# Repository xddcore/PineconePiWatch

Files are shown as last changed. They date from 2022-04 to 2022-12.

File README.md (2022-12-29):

<!--
 * @Author: Chengsen Dong 1034029664@qq.com
 * @Date: 2022-12-29 07:08:10
 * @LastEditors: Chengsen Dong 1034029664@qq.com
 * @LastEditTime: 2022-12-29 07:17:54
 * @FilePath: /undefined/Users/xdd/git_warehouse/PineconePiWatch/README.md
 * @Description: 这是默认设置,请设置`customMade`, 打开koroFileHeader查看配置 进行设置: https://github.com/OBKoro1/koro1FileHeader/wiki/%E9%85%8D%E7%BD%AE
-->
# PineconePi Watch:一个基于ESP32+STC8的物联网手表
## 作者:xddcore(Chengsen Dong)|大二课程系统设计
## Email:1034029664@qq.com
## Github:www.github.com/xddcore
## Version:1.2
## Date:20/04/2021
## 效果视频:https://www.bilibili.com/video/BV1AA411V7fJ?spm_id_from=333.999.0.0
## 中期视频(ppt讲解):https://www.bilibili.com/video/BV1XT4y1P718/?share_source=copy_web&vd_source=e0a08236a93074f4e5ffc9911edd0047

# 项目简介
**PineconePi Watch** ESP32+STC8；6轴陀螺仪+心率+体温；MQTT；双层0603 SMD电路板；两块电路板FPC连接；1.44英寸OLED显示屏；拨动开关；IP5306+500maH可充电锂电池；Type-C可二次开发；

# 项目特性
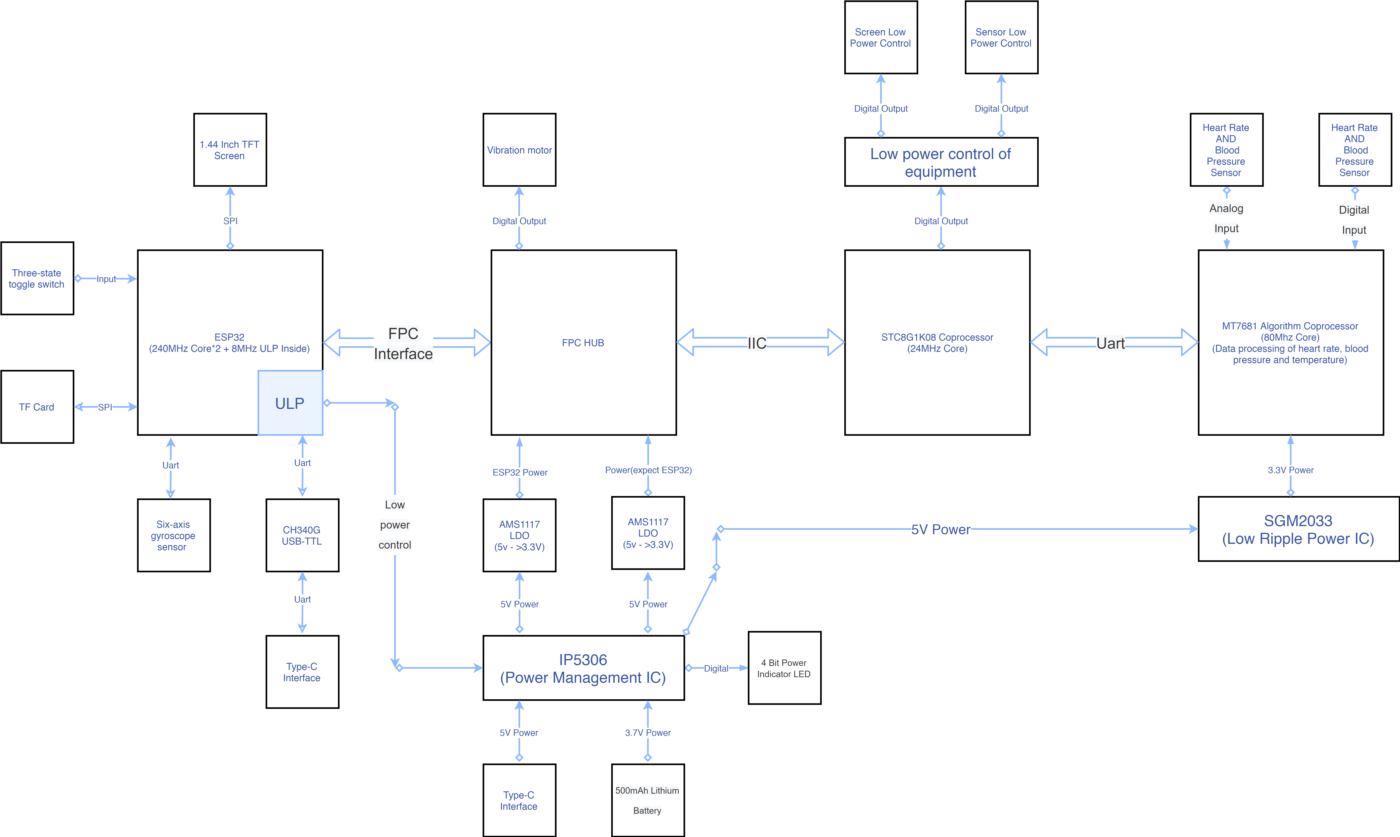
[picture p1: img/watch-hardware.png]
项目硬件框图


为了更加直观的展示项目的硬件结构，将项目硬件框图展示如上。现在将对硬件框图进行详细的介绍：
1.	本设备硬件由3个微控制器，5个核心组成。其中ESP32与STC8协处理器通过FPC排线连接。它们使用IIC通信协议进行通信和数据传输。
2.	设备电源由IP5306电源管理芯片进行管理。IP5306可以根据实际情况自动选择设备电源由TYPE-C接口提供或由内部500mAh锂电池提供。同时，IP5306电源管理芯片还可以为锂电池进行充电，并通过4位LED灯指示设备电量。
3.	程序下载和与计算机的串口通信通过CH340G USB-TTL芯片将USB电平和TTL电平进行转换。
4.	ESP32内部的8MHz ULP处理器主要用于当设备休眠时，控制设备的低功耗功能。
5.	STC8协处理器主要用于处理MT7681算法芯片通过串口传输过来的数据，并将数据通过IIC协议传输至ESP32中。同时STC8协处理器对设备TFT屏幕的电源以及传感器的电源进行控制。
6.	用户通过3状态拨码开关控制设备。
7.	MT7681算法芯片读取心率血压传感器和体温传感器的数据，并通过串口将数据传输给STC8协处理器。

# 软件流程图(充分利用ESP32双核+ULP低功耗小核）

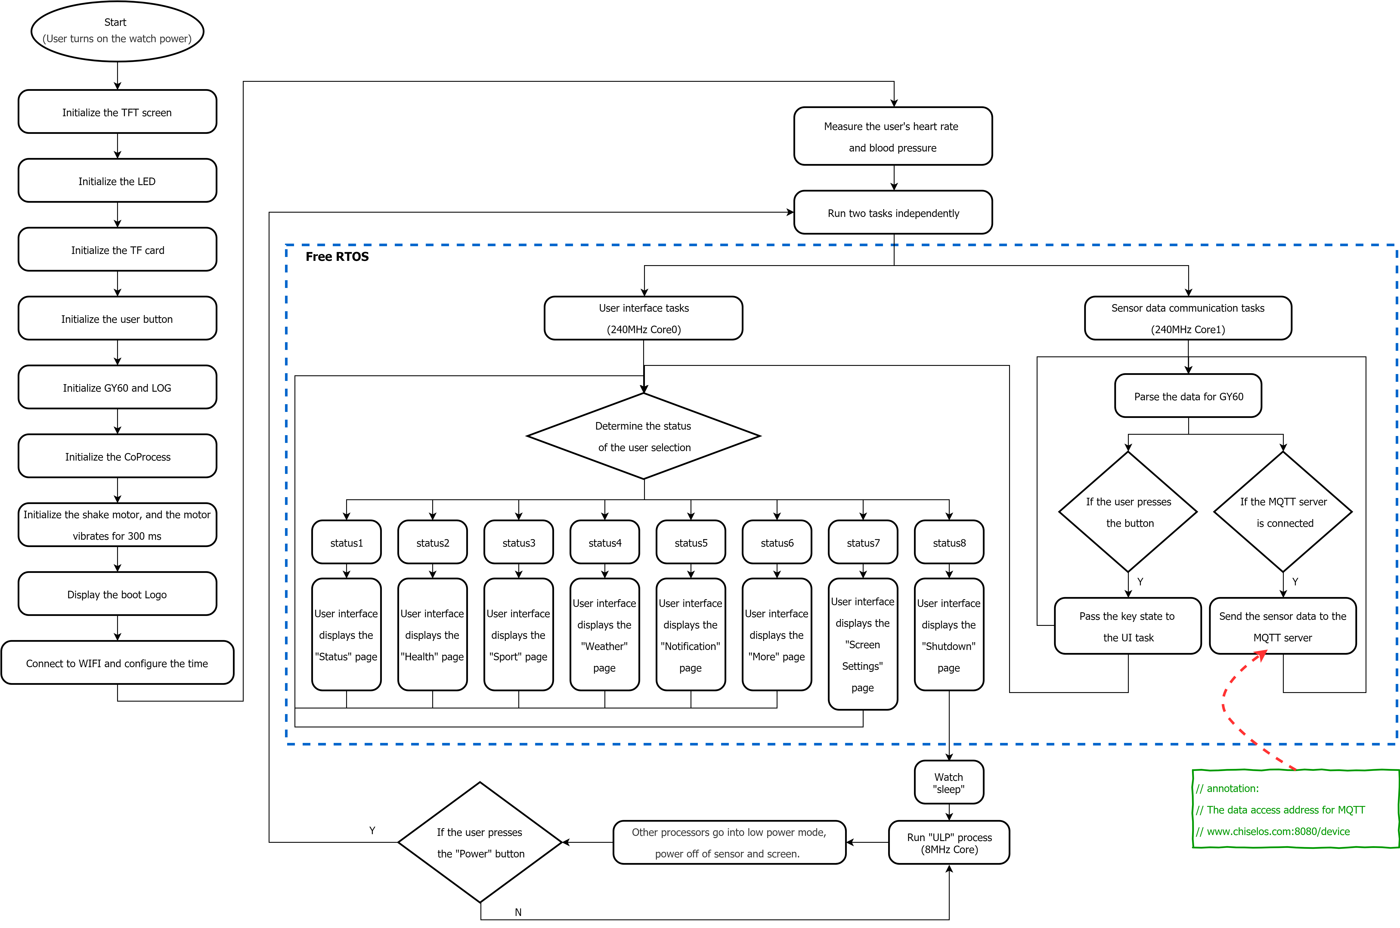
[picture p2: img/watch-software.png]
软件流程图


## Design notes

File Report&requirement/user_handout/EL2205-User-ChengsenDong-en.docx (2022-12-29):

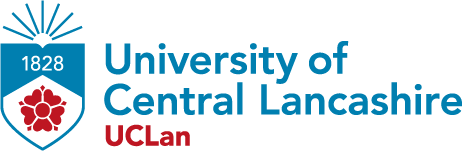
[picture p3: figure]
Where opportunity creates success - University of Central Lancashire

PineconePi Watch

Instruction set & user guide

Chengsen Dong

G20841536

Electronic Systems Applications

EL2205

Zhijie Ding

14/04/2021

I confirm that the present assignment is all my own work and the source of any information and material I have used (including the Internet) has been fully identified and properly acknowledged as required in the School guidelines I have received.

Signed: Chengsen Dong

# 1. How to use PineconePi Watch

## 1.1 Self-test

After PineconePi Watch is turned on, it will start the initialization of each peripheral in turn. At the same time, after completing the initialization of the peripheral, the device will also detect the online status of the peripheral. If the initialization of the peripheral and the online detection of the peripheral are completed, a blue X will be drawn on the corresponding peripheral position on the TFT screen. If there is an error in this process, a blue X will not be drawn on the corresponding peripheral position on the TFT screen. This power-on self-test operation helps users check out the abnormal parts of the device, and facilitates users to troubleshoot problems.

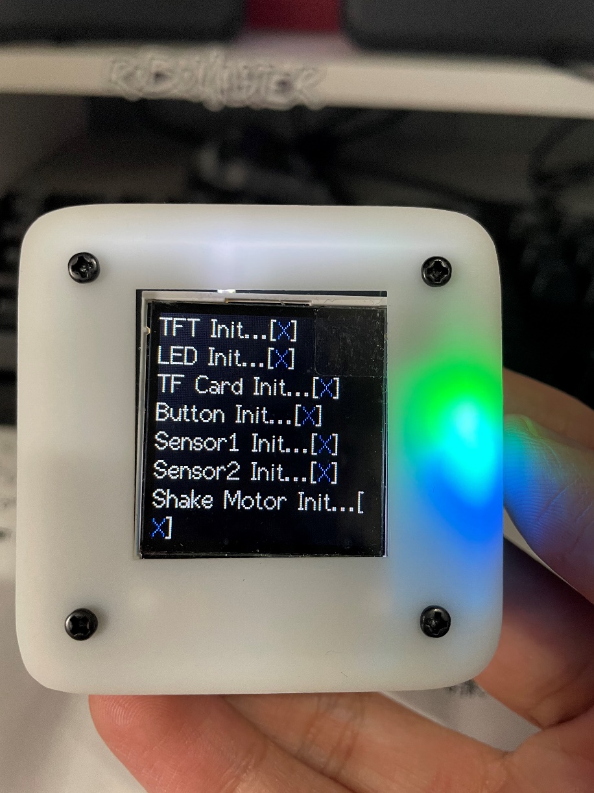
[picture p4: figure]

Figure 1 Power-on self-test

## 1.2 Use the toggle switch to control the device

There is a 3-state toggle switch in the upper left corner of the PineconePi Watch. This toggle switch is used to allow the user to control the device to collect the required sensor data. The control logic of the toggle switch is as follows: when the toggle switch is moved down, the device jumps to the next interface; when the toggle switch is moved up, the device jumps to the previous interface; when the toggle switch is pressed, The device enters the secondary menu interface of the current interface.

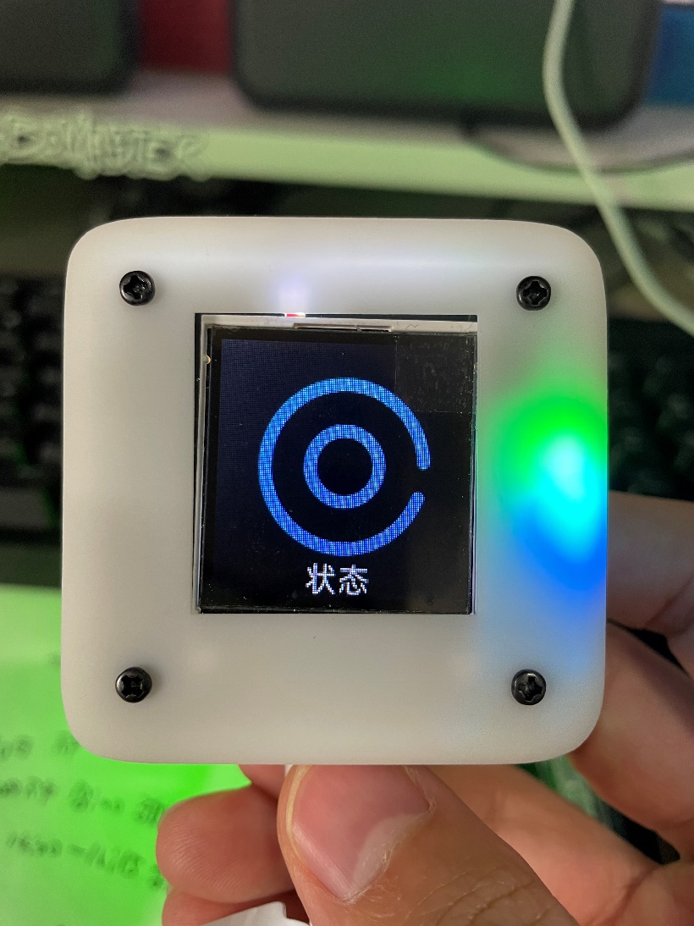
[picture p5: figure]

Figure 2 Toggle switch control equipment

## 1.3 Viewing sensor data

To facilitate the reading of sensor values, I put all sensor data on the 8th interface for display. At the same time, in order to enable the sensor data to be transmitted to the MQTT server through the WIFI hotspot connected when the machine is turned on, and to display the sensor data on the Web page. I added NTP time service to the 8th interface to synchronously detect the WIFI connection. If the Dongba District (Beijing) time can be displayed normally on the 8th interface, it proves that the device has been connected to the Internet at this time.

In the 8th interface, the highest blood pressure, lowest blood pressure, heart rate, body temperature will be displayed; X-axis angle and acceleration; Y-axis angle and acceleration; Z-axis angle and acceleration.

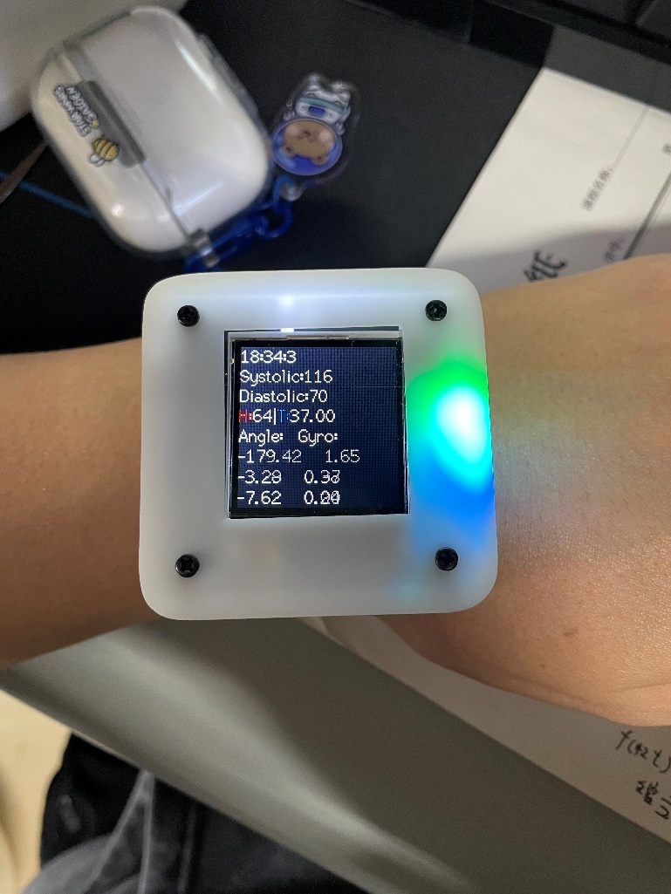
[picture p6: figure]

Figure 3 View of sensor data

## 1.4 View device data on the web page

When the device is on the 8th interface, the device will send the collected sensor data to the MQTT server. At the same time, the web server Django script that has been running will display the data monitored from MQTT to the web page (web page address: www.chiselos.com:8080/device/). Every time the web page is refreshed, the device will report the latest sensor data to the MQTT server, and this latest data will be used to update the data displayed on the web page.

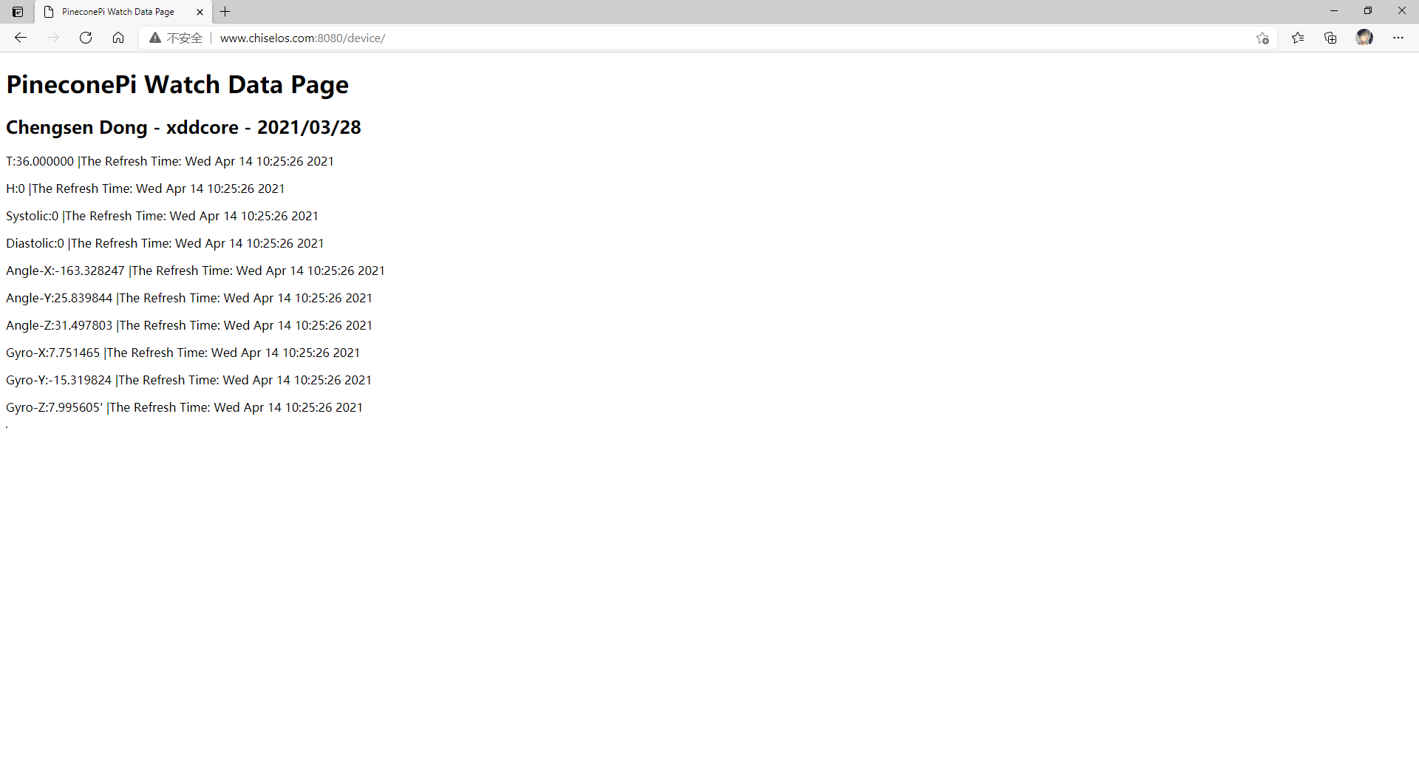
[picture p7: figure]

Figure 4 Web page data view

## 1.5 Update device firmware

PineconePi Watch comes with an automatic firmware download circuit inside. When updating the firmware, you only need to connect the device and the computer through a TYPE-C cable. Then you can download the compiled .bin program file to the device. At the same time, the device also supports an over-the-air upgrade (OTA) function. As long as the device is connected to the Internet, it can compare its firmware version number with the firmware version number on the server. If the device version number is lower than the server version number. The device will automatically download the latest firmware from the server to the device TF card, and then the device will burn the firmware in the TF card into the ESP32 on-chip FLASH.

## 1.6 Battery indicator and charging

There are 4 power indicator lights on the PCB at the bottom of the PineconePi Watch, and each LED light represents 25% of the power. For example, when the power is 50%-75%, 2 LEDs will light up; when the power is 75%-100%, 3 LEDs will light up; when the power reaches 100%, there will be 4 LEDs Glow.

PineconePi Watch has a powerful IP5306 power management chip inside. Just connect the TYPE-C cable to the 5V DC power supply and you can start charging the device. When the device is charging, the corresponding power LED light will flash to indicate. When it is full, the LED light will no longer flash.

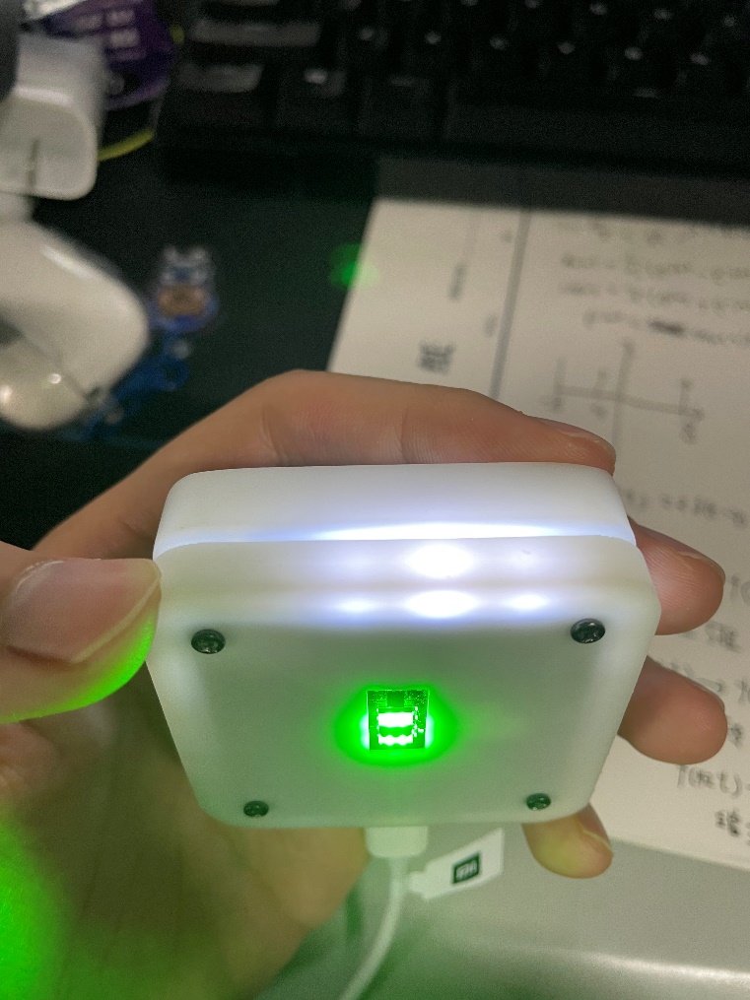
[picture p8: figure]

Figure 5 Power and charging indication

# 2. Troubleshooting Guide

Due to the complexity of this equipment, the following failures occur when in use, please return it to me for repair. The following failure guide only helps users to know the cause of the failure:

## 2.1 Self-test failed

When an error occurs in the device's self-test, please troubleshoot the fault in the following ways:

1. Sensor1 self-detection error. Possible reasons for this error:

1. ICM 6-axis gyroscope sensor is not connected

2. Sensor2 self-test error. Possible reasons for this error:

1. STC8 coprocessor is not working

2. STC8 coprocessor

## 2.2 Graphical interface cannot be displayed

When the graphical interface of the device cannot be displayed, the possible reasons for this error:

1. The TF card with system file resources is not inserted

2. TF insertion appears loose

3. The TF card does not contain system file resources

## 2.3 Unable to get sensor value

When the device cannot display sensor data on the 8th interface, the possible reasons for this error are:

1. The device is not connected to WIFI

2. WIFI cannot connect to the Internet

3. NTP time service failed

4. Sensor failure

## 2.4 Web page access failed

When the web page cannot be accessed, the possible reasons for this error:

1. The access URL is incorrectly entered

2. The web server is not working

3. Web server failure

## 2.5 Unable to start device

When the device fails to start, the possible reasons for this error:

1. The internal lithium battery power of the device is exhausted

2. Equipment failure

3. The equipment power management circuit works abnormally

Running head 2

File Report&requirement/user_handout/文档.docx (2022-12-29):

在PineconePi Watch开机后，便会依次开始对每一个外设的初始化。同时，在完成对外设的初始化后，设备还会对外设的在线情况进行检测。如果外设初始化和外设在线检测完成，便会在TFT屏幕上的相应外设位置绘制蓝色X。如果这一个过程出现错误，便不会在TFT屏幕上的相应外设位置绘制蓝色X。这个上电自检测操作有助于帮助用户检查出设备中运行不正常的部分，方便用户排除问题。

PineconePi Watch左上角带有一颗3状态拨动开关。这颗拨动开关用于让用户控制设备采集需要的传感器数据。拨动开关的控制逻辑如下：当波动开关向下拨动时，设备跳转到下一个界面；当拨动开关向上拨动时，设备跳转到上一个界面；当拨动开关按下时，设备进入当前界面的二级菜单界面。

为了方便读取传感器数值，我将所有传感器数据放在8号界面中显示。同时，为了使传感器数据能够通过开机时连接的WIFI热点传输至MQTT服务器中，并把传感器数据显示在Web网页上面。我在8号界面中加入了NTP授时来同步检测WIFI联通情况。如果在8号界面中能够正常显示东八区(北京)时间，则证明此时设备已经连接上互联网。

在8号界面中，将会显示最高血压，最低血压，心率，体温；X轴角度和加速度；Y轴角度和加速度；Z轴角度和加速度。

当设备处于8号界面时，设备会将采集到的传感器数据发送至MQTT服务器中。同时，一直处于运行状态中的Web服务器Django脚本将会把从MQTT中监听到的数据显示到Web网页中（网页地址：www.chiselos.com:8080/device/）。每刷新一次网页，设备将会把最新的传感器数据上报到MQTT服务器中，这个最新的数据将用于更新Web网页上显示的数据。

PineconePi Watch内部自带固件自动下载电路。更新固件时，只需要将设备与计算机通过TYPE-C线缆进行连接。之后便可以将编译过后的.bin程序文件下载到设备中。同时，设备还支持空中升级(OTA)功能，设备只要连接上互联网，便可以将自己的固件版本号与服务器上的固件版本号进行对比。如果设备版本号低于服务器版本号。设备将会自动将最新的固件从服务器中下载到设备TF卡中，设备再将TF卡中的固件烧入ESP32片内FLASH中。

PineconePi Watch底部PCB上带有4颗电量指示灯，每颗LED灯代表25%的电量。例如当电量为50%-75%时，将会有2颗LED发光；当电量为75%-100%时，将会有3颗LED发光；当电量达到100%时，将会有4颗LED发光。

PineconePi Watch内部带有强大的IP5306电源管理芯片。只需将TYPE-C线缆与5V DC电源连接，便可以开始为设备充电。设备充电时，对应的电量LED灯将会闪烁提示。充满时，LED灯将不会再闪烁。

——

当设备在自检测中出现错误时，请以以下方式排除故障：

1. Sensor1自检测错误。可能导致这个错误的原因：
1. ICM 6轴陀螺仪传感器未连接

2．Sensor2自检测错误。可能导致这个错误的原因：

1. STC8 协处理器未工作

2.STC8协处理器

当设备图形化界面无法显示时，可能导致这个错误的原因：

1. 装有系统文件资源的TF卡未插入
2. TF插入出现松动
3. TF卡中未含有系统文件资源

当设备无法在8号界面上显示传感器数据时，可能导致这个错误的原因：

1. 设备未连接WIFI
2. WIFI无法连接互联网
3. NTP授时失败
4. 传感器故障

当Web网页无法访问时，可能导致这个错误的原因：

1. 未正确输入访问网址
2. Web服务器未工作
3. Web服务器故障

当设备无法启动时，可能导致这个错误的原因：

1． 设备内部锂电池电源耗尽
2． 设备故障
3． 设备电源管理电路工作异常

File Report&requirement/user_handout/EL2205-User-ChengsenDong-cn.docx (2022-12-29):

Where opportunity creates success - University of Central Lancashire

PineconePi Watch

Instruction set & user guide

Chengsen Dong

G20841536

Electronic Systems Applications

EL2205

Zhijie Ding

14/04/2021

I confirm that the present assignment is all my own work and the source of any information and material I have used (including the Internet) has been fully identified and properly acknowledged as required in the School guidelines I have received.

Signed: Chengsen Dong

# 1. PineconePi Watch使用指南

## 1.1 开机自检测

在PineconePi Watch开机后，便会依次开始对每一个外设的初始化。同时，在完成对外设的初始化后，设备还会对外设的在线情况进行检测。如果外设初始化和外设在线检测完成，便会在TFT屏幕上的相应外设位置绘制蓝色X。如果这一个过程出现错误，便不会在TFT屏幕上的相应外设位置绘制蓝色X。这个上电自检测操作有助于帮助用户检查出设备中运行不正常的部分，方便用户排除问题。


图1 开机自检测

## 1.2 使用拨动开关控制设备

PineconePi Watch左上角带有一颗3状态拨动开关。这颗拨动开关用于让用户控制设备采集需要的传感器数据。拨动开关的控制逻辑如下：当波动开关向下拨动时，设备跳转到下一个界面；当拨动开关向上拨动时，设备跳转到上一个界面；当拨动开关按下时，设备进入当前界面的二级菜单界面。


图2 拨动开关控制设备

## 1.3 传感器数据查看

为了方便读取传感器数值，我将所有传感器数据放在8号界面中显示。同时，为了使传感器数据能够通过开机时连接的WIFI热点传输至MQTT服务器中，并把传感器数据显示在Web网页上面。我在8号界面中加入了NTP授时来同步检测WIFI联通情况。如果在8号界面中能够正常显示东八区(北京)时间，则证明此时设备已经连接上互联网。

在8号界面中，将会显示最高血压，最低血压，心率，体温；X轴角度和加速度；Y轴角度和加速度；Z轴角度和加速度。


图3 传感器数据查看

## 1.4 Web网页查看设备数据

当设备处于8号界面时，设备会将采集到的传感器数据发送至MQTT服务器中。同时，一直处于运行状态中的Web服务器Django脚本将会把从MQTT中监听到的数据显示到Web网页中（网页地址：www.chiselos.com:8080/device/）。每刷新一次网页，设备将会把最新的传感器数据上报到MQTT服务器中，这个最新的数据将用于更新Web网页上显示的数据。


图4 Web 网页数据查看

## 1.5 更新设备固件

PineconePi Watch内部自带固件自动下载电路。更新固件时，只需要将设备与计算机通过TYPE-C线缆进行连接。之后便可以将编译过后的.bin程序文件下载到设备中。同时，设备还支持空中升级(OTA)功能，设备只要连接上互联网，便可以将自己的固件版本号与服务器上的固件版本号进行对比。如果设备版本号低于服务器版本号。设备将会自动将最新的固件从服务器中下载到设备TF卡中，设备再将TF卡中的固件烧入ESP32片内FLASH中。

## 1.6 电量指示与充电

PineconePi Watch底部PCB上带有4颗电量指示灯，每颗LED灯代表25%的电量。例如当电量为50%-75%时，将会有2颗LED发光；当电量为75%-100%时，将会有3颗LED发光；当电量达到100%时，将会有4颗LED发光。

PineconePi Watch内部带有强大的IP5306电源管理芯片。只需将TYPE-C线缆与5V DC电源连接，便可以开始为设备充电。设备充电时，对应的电量LED灯将会闪烁提示。充满时，LED灯将不会再闪烁。


图5 电量与充电指示

# 2. 故障排除指南

## 2.1自检测失败

当设备在自检测中出现错误时，请以以下方式排除故障：

1.Sensor1自检测错误。可能导致这个错误的原因：

1.ICM 6轴陀螺仪传感器未连接

2．Sensor2自检测错误。可能导致这个错误的原因：

1. STC8 协处理器未工作

2.STC8协处理器

## 2.2 图形界面无法显示

当设备图形化界面无法显示时，可能导致这个错误的原因：

1.装有系统文件资源的TF卡未插入

2.TF插入出现松动

3.TF卡中未含有系统文件资源

## 2.3 无法获取传感器数值

当设备无法在8号界面上显示传感器数据时，可能导致这个错误的原因：

1.设备未连接WIFI

2.WIFI无法连接互联网

3.NTP授时失败

4.传感器故障

## 2.4 Web网页访问失败

当Web网页无法访问时，可能导致这个错误的原因：

1.未正确输入访问网址

2.Web服务器未工作

3.Web服务器故障

## 2.5 无法启动设备

当设备无法启动时，可能导致这个错误的原因：

1．设备内部锂电池电源耗尽

2．设备故障

3．设备电源管理电路工作异常

Running head 2

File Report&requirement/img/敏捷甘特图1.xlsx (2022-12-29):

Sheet: 甘特
在此工作表中创建甘特图。 在单元格 B1 中输入此项目的标题。 图例标题位于单元格 I1 中。 有关如何使用此工作表（包括屏幕阅读器的说明）以及此工作簿作者的信息包含在“关于”工作表中。 继续向下浏览 A 列，获取进一步指示。 | PineconePi Watch |  |  |  |  |  | Legend:
在单元格 B2 中输入公司名称。 图例位于单元格 I2 到 AC2 中。 | Chengsen Dong |  |  |  |  |  | Low priority |  |  |  |  | Medium priority |  |  |  |  | High priority |  |  |  |  | 高风险 |  |  |  |  | 未分配
在单元格 B3 中输入项目负责人的姓名。在单元格 F3 中输入项目开始日期，或允许示例公式从“甘特数据”表中查找最小日期值。 项目开始日期：标签位于单元格 D3 中。 | EL2205 |  | Project start date: |  | 2020-11-04
滚动增量位于单元格 F4 中。 从单元格 I4 开始到单元格 BL4，显示第 5 行中日期的月份。 请勿修改这些单元格。它们根据单元格 F3 中的项目开始日期自动更新。 |  |  | Scroll delta: |  | 0 |  | 11月 |  |  |  |  |  |  |  |  |  |  |  |  |  |  |  |  |  |  |  |  |  |  |  |  |  |  |  | 12月
单元格 I5 到 BL5 包含每个日期单元格上方单元格块中表示的“月”的当月日期数字，这些数字是自动计算得出的。 请勿修改这些单元格。 今天的日期带有红色（十六进制 #AD3815）轮廓（从第 5 行中显示今天日期的列及至项目安排结尾的该列）。 |  |  |  |  |  |  | 2020-11-04 | 2020-11-05 | 2020-11-06 | 2020-11-07 | 2020-11-08 | 2020-11-09 | 2020-11-10 | 2020-11-11 | 2020-11-12 | 2020-11-13 | 2020-11-14 | 2020-11-15 | 2020-11-16 | 2020-11-17 | 2020-11-18 | 2020-11-19 | 2020-11-20 | 2020-11-21 | 2020-11-22 | 2020-11-23 | 2020-11-24 | 2020-11-25 | 2020-11-26 | 2020-11-27 | 2020-11-28 | 2020-11-29 | 2020-11-30 | 2020-12-01 | 2020-12-02 | 2020-12-03 | 2020-12-04 | 2020-12-05 | 2020-12-06 | 2020-12-07 | 2020-12-08 | 2020-12-09 | 2020-12-10 | 2020-12-11 | 2020-12-12 | 2020-12-13 | 2020-12-14 | 2020-12-15 | 2020-12-16 | 2020-12-17 | 2020-12-18 | 2020-12-19 | 2020-12-20 | 2020-12-21 | 2020-12-22 | 2020-12-23 | 2020-12-24 | 2020-12-25
滚动条位于单元格 I6 到 BL6 中。数据分页增量定义为一次 2 页，可以在控制栏的设置中配置该增量。 若要在时间线中向前或向后跳转，请在单元格 F4 中输入 0 或更大的值。 值为 0 会转到图表的开头。
此行包含其后面的项目安排的标题。 从 B7 导航到 BL7 以听取内容。该标题上方日期一周中每一天的首字母，从单元格 I7 开始，直到单元格 BL7。 所有项目时间线制图都是根据“里程碑”表中输入的类别、开始日期和天数自动生成的。 | Mission statement | category | personnel | progress | Start date | Number of days | 三 | 四 | 五 | 六 | 日 | 一 | 二 | 三 | 四 | 五 | 六 | 日 | 一 | 二 | 三 | 四 | 五 | 六 | 日 | 一 | 二 | 三 | 四 | 五 | 六 | 日 | 一 | 二 | 三 | 四 | 五 | 六 | 日 | 一 | 二 | 三 | 四 | 五 | 六 | 日 | 一 | 二 | 三 | 四 | 五 | 六 | 日 | 一 | 二 | 三 | 四 | 五
请勿删除此行。隐藏了此行，以保留用于突出显示项目安排中当天的公式。
在单元格 B9 到 G9 中输入项目信息。 示例数据位于单元格 B9 到 G33 中。 输入“里程碑说明”，从下拉列表中选择一个类别，为某人分配责任人，输入进度、开始日期和任务的天数以开始制图。 下一条指示位于单元格 A34 中。 | Hardware development
 | 元件选型 | 中等风险 | ChengsenDong | 100% | 2020-11-04 | 6
 | 原理图绘制 | 中等风险 | ChengsenDong | 100% | 2020-11-10 | 4
 | PCB绘制 | 中等风险 | ChengsenDong | 100% | 2020-11-14 | 6
 | PCB焊接 | 中等风险 | ChengsenDong | 100% | 2020-11-20 | 2
 | 外壳设计 | 中等风险 | ChengsenDong | 100% | 2020-11-22 | 2
 | 整体组装 | 中等风险 | ChengsenDong | 100% | 2020-11-24 | 1
 | Software development
 | ESP32软件编写 | 低风险 | ChengsenDong | 100% | 2020-11-25 | 5
 | STC协处理器软件编写 | 低风险 | ChengsenDong | 100% | 2020-11-30 | 3
 | Web服务器代码编写 | 低风险 | ChengsenDong | 100% | 2020-12-03 | 3
 | 整体软件编写 | 低风险 | ChengsenDong | 100% | 2020-12-06 | 2
 | Test
 | 硬件测试 | 步入正轨 | ChengsenDong | 100% | 2020-12-08 | 4
 | Web服务器测试 | 步入正轨 | ChengsenDong | 100% | 2020-12-12 | 2
 | 整体测试 | 步入正轨 | ChengsenDong | 100% | 2020-12-14 | 3
 | Report writing
 | Development Report Preparation | 高风险 | ChengsenDong | 100% | 2020-12-17 | 5
 | User manual preparation | 高风险 | ChengsenDong | 100% | 2020-12-22 | 3
这是一个空行

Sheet: 关于
关于此模板
此模板提供了一种创建甘特图的简单方法，可帮助直观呈现和跟踪项目。只需输入任务说明，选择一种类别（“目标”、“里程碑”、“步入正轨”、“低风险”、“中等风险”、“高风险”），然后输入任务完成百分比进度、开始日期和完成任务的天数。甘特图填充完毕，并经过颜色编码，可帮助区分各种类别。通过滚动条可滚动时间线。通过插入新行插入新任务。
屏幕阅读器指南
此工作簿中有 2 个工作表。 甘特图 关于 每个工作表的指示文本位于每个工作表中自单元格 A1 开始的 A 列中。这些指示都使用隐藏文本编写。每个步骤均提供相应指示，引导阅读者查看行中的相应信息。除非另有明确指示，否则会在单元格 A2、A3 等后续单元格中持续指示相应步骤。例如，指示文本可能显示为“转到单元格 A6”以执行下一步操作。 将不会打印此隐藏文本。 若要从工作表删除这些指示，只需删除 A 列即可。
这是此工作表中的最后一条指示。
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

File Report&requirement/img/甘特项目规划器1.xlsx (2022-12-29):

Project Schedule
在右侧选择要突出显示的周期。描述图表的图例如下所示。 |  |  |  |  | 周期突出显示： | 1 |  |  | 计划工期 |  |  |  |  |  | 实际开始时间 |  |  |  |  | 完成百分比 |  |  |  |  | 实际（超出计划） |  |  |  |  |  |  |  | 完成（超出计划）百分比
活动 | 计划开始时间 | 计划工期 | 实际开始时间 | 实际工期 | 完成百分比 | 周期
 |  |  |  |  |  | 1 | 2 | 3 | 4 | 5 | 6 | 7 | 8 | 9 | 10 | 11 | 12 | 13 | 14 | 15 | 16 | 17 | 18 | 19 | 20 | 21 | 22 | 23 | 24 | 25 | 26 | 27 | 28 | 29 | 30 | 31 | 32 | 33 | 34 | 35 | 36 | 37 | 38 | 39 | 40 | 41 | 42 | 43 | 44 | 45 | 46 | 47 | 48 | 49 | 50 | 51 | 52 | 53
活动 01 | 1 | 5 | 1 | 4 | 25%
活动 02 | 1 | 6 | 1 | 6 | 100%
活动 03 | 2 | 4 | 2 | 5 | 35%
活动 04 | 4 | 8 | 4 | 6 | 10%
活动 05 | 4 | 2 | 4 | 8 | 85%
活动 06 | 4 | 3 | 4 | 6 | 85%
活动 07 | 5 | 4 | 5 | 3 | 50%
活动 08 | 5 | 2 | 5 | 5 | 60%
活动 09 | 5 | 2 | 5 | 6 | 75%
活动 10 | 6 | 5 | 6 | 7 | 100%
活动 11 | 6 | 1 | 5 | 8 | 60%
活动 12 | 9 | 3 | 9 | 3 | 0%
活动 13 | 9 | 6 | 9 | 7 | 50%
活动 14 | 9 | 3 | 9 | 1 | 0%
活动 15 | 9 | 4 | 8 | 5 | 1%
活动 16 | 10 | 5 | 10 | 3 | 80%
活动 17 | 11 | 2 | 11 | 5 | 0%
活动 18 | 12 | 6 | 12 | 7 | 0%
活动 19 | 12 | 1 | 12 | 5 | 0%
活动 20 | 14 | 5 | 14 | 6 | 0%
活动 21 | 14 | 8 | 14 | 2 | 44%
活动 22 | 14 | 7 | 14 | 3 | 0%
活动 23 | 15 | 4 | 15 | 8 | 12%
活动 24 | 15 | 5 | 15 | 3 | 5%
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

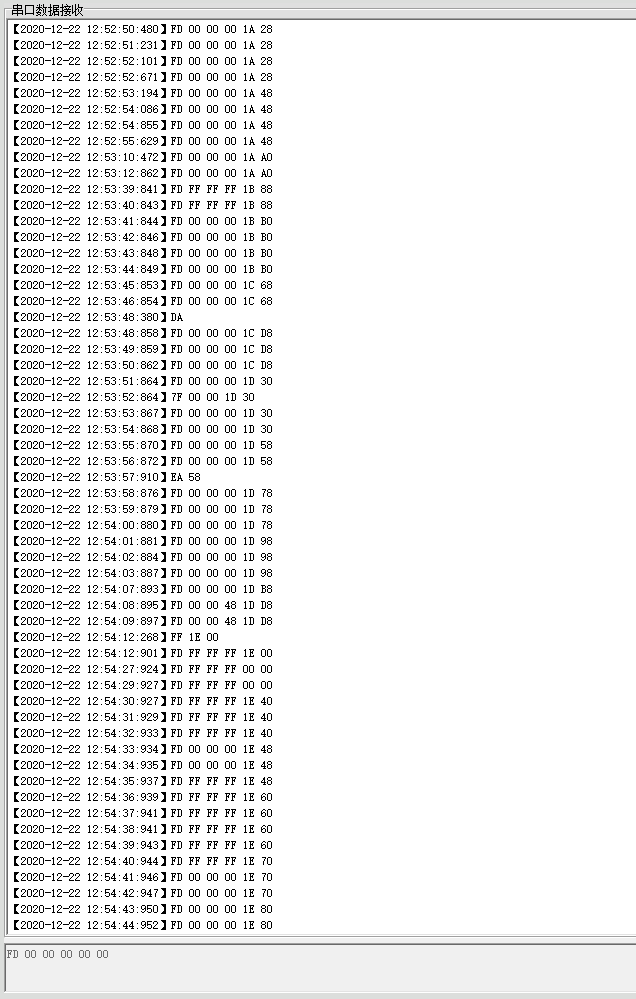
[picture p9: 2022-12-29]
Report&requirement/img/心率回传.png

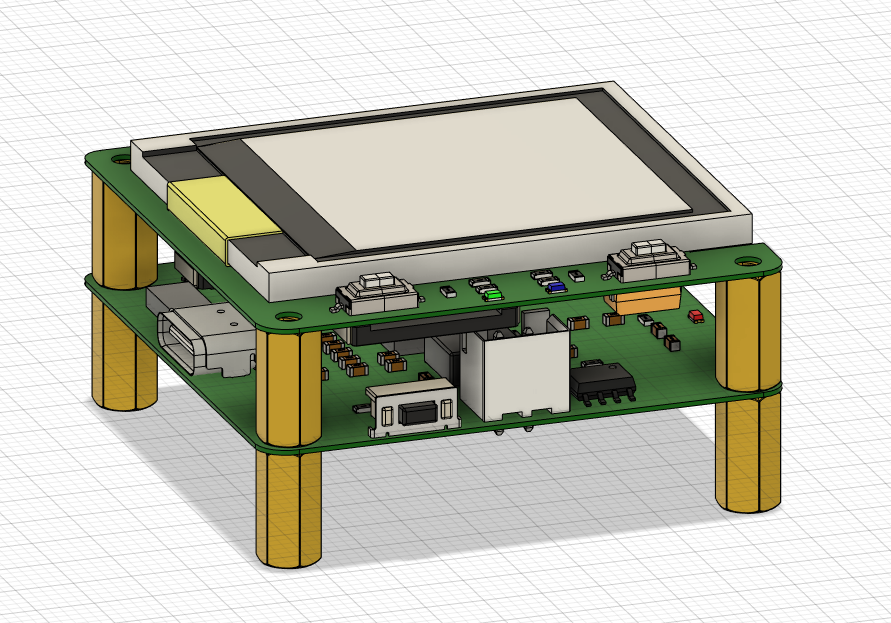
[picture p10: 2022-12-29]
Report&requirement/img/PCB3d仿真图2.png

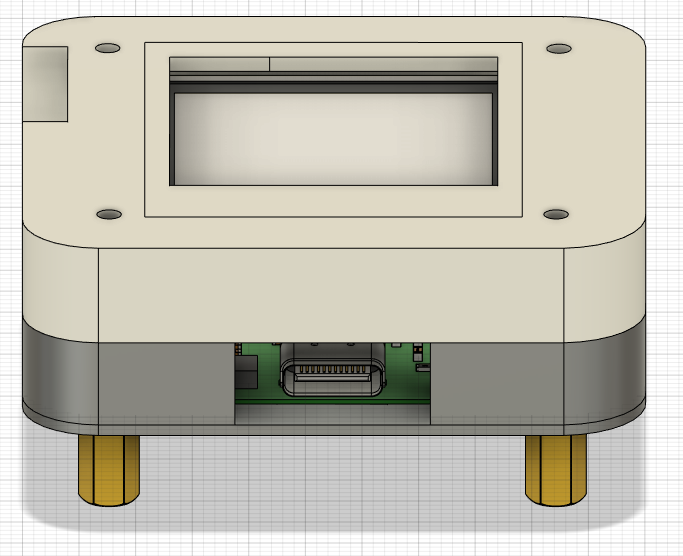
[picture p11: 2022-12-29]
Report&requirement/img/带外壳3d仿真图.png

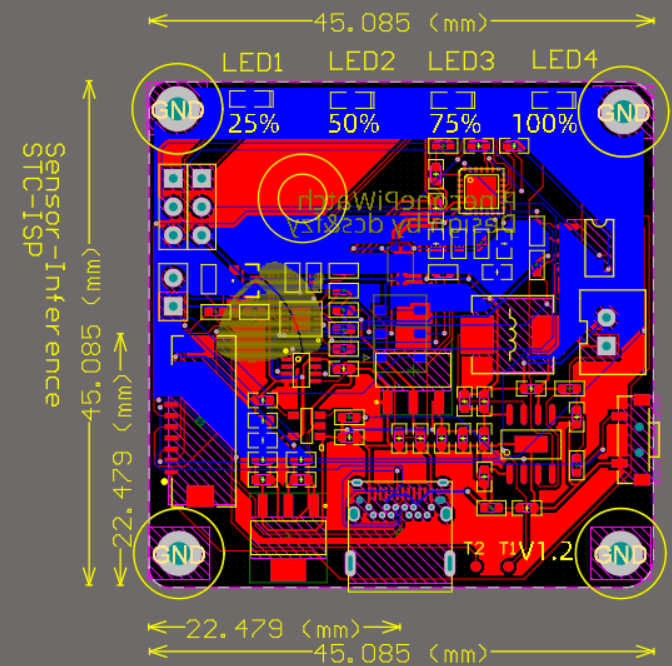
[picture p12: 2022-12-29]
Report&requirement/img/BOTTOM-PCB.png

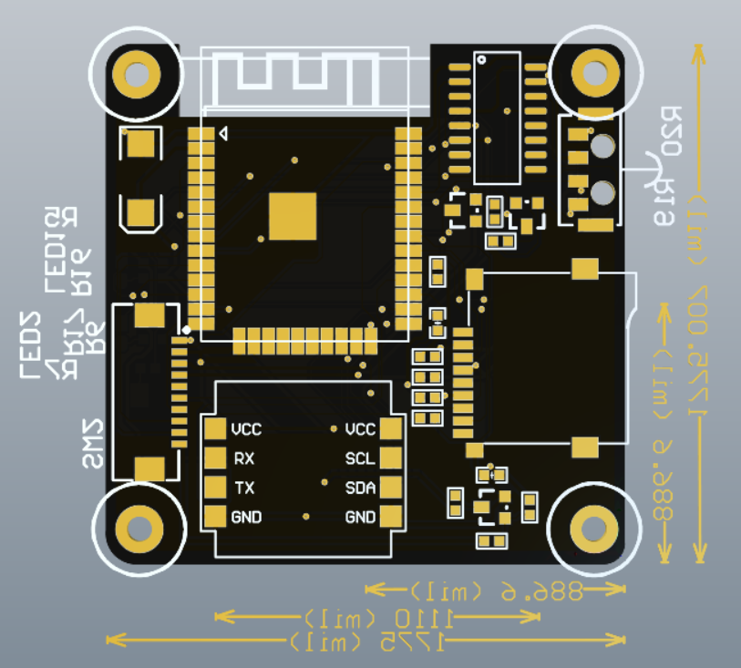
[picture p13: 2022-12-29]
Report&requirement/img/TOP-PCB-2.png

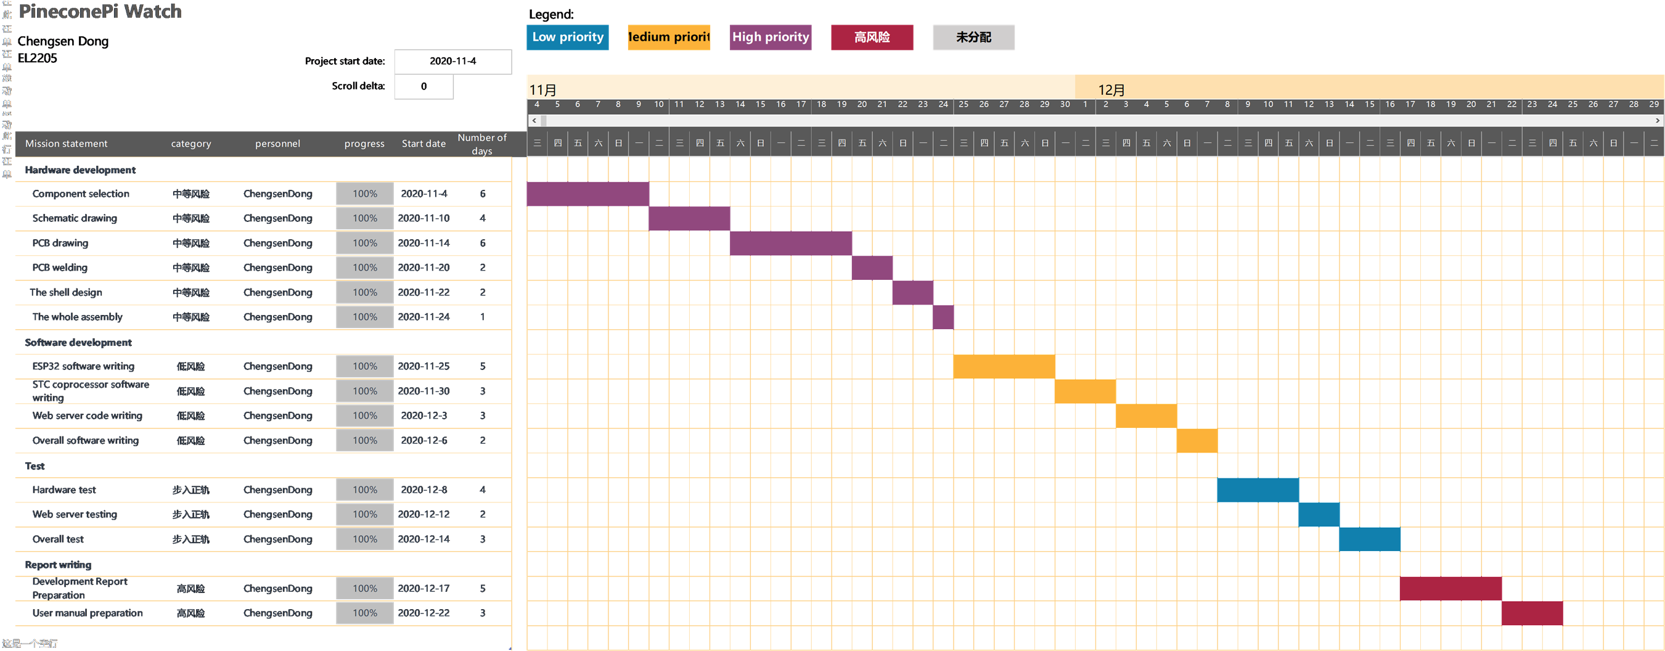
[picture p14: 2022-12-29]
Report&requirement/img/甘特图.png

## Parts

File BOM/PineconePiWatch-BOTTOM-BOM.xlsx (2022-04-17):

Comment | Description | Designator | Footprint | LibRef | Quantity
电池接口 | Header, 2-Pin, Right Angle | BT1 | XH2.54-LI-2P | Header 2H | 1
10uF | Capacitor | C1, C2, C6, C7, C8, C10, C16, C22, C24 | C 0603_L | Cap | 9
22uF | Capacitor | C3, C4, C5 | C 0603_L | Cap | 3
0.1uF | Capacitor | C9, C11, C23, C25 | C 0603_L | Cap | 4
100nF | Capacitor | C12, C13, C14, C15, C17, C21 | C 0603_L | Cap, Cap_1 | 6
220nF | Capacitor | C18 | C 0603_L | Cap_1 | 1
2.2uF | Capacitor | C19 | C 0603_L | Cap_1 | 1
2.2nF | Capacitor | C20 | C 0603_L | Cap_1 | 1
HDR-1X10 | 10P接插件 | FPC1 | FPC1.0-2H-WS-10P | Header 10 | 1
1uH | Inductor | L1 | L-SMD-0630 | Inductor | 1
25% | Typical INFRARED GaAs LED | LED1 | LED 0603R | LED0 | 1
50% | Typical INFRARED GaAs LED | LED2 | LED 0603R | LED0 | 1
75% | Typical INFRARED GaAs LED | LED3 | LED 0603R | LED0 | 1
100% | Typical INFRARED GaAs LED | LED4 | LED 0603R | LED0 | 1
SS8050 | 高频放大-NPN型 | Q1 | SOT-23 | 8050-SMD | 1
2R | Resistor | R1, R2 | R 0603_L | Res2 | 2
10K | Resistor, 贴片电阻 | R3, R5, R9, R22 | R 0603_L | Res2, R | 4
1K | 贴片电阻 | R4 | R 0603_L | R | 1
10 | 贴片电阻 | R6 | R 0603_L | R | 1
4.7K | 贴片电阻 | R7, R8 | R 0603_L | R | 2
100R | Resistor | R10, R11 | C 0603_L | Res2 | 2
0 | Resistor | R12 | R 0603-HP_L | Res2 | 1
120K | Resistor | R13 | R 0603_L | Res2 | 1
22K | Resistor | R14 | R 0603_L | Res2 | 1
3.3K | Resistor | R15 | R 0603_L | Res2 | 1
7.5M | Resistor | R16 | R 0603_L | Res2 | 1
6.2M | Resistor | R17 | R 0603_L | Res2 | 1
4.7M | Resistor | R18 | R 0603_L | Res2 | 1
3.3M | Resistor | R19 | R 0603_L | Res2 | 1
160R | Resistor | R20, R21 | R 0603_L | Res2 | 2
HDR-1X3 | 3P接插件 | Sensor-Inference, STC-ISP | HDR2.54-LI-3P | Header 3 | 2
3x6x5 | 3x6轻触开关 | SW1 | TSW 3*6*4.3-S-W | TSW 3x6 | 1
Test_Point |  | T1, T2 | TP_1_0MM | TP | 2
IP5306 |  | U1 | IP5306 | IP5306 | 1
AMS1117-3V3 | 三端稳压芯片 | U2, U10 | SOT223_L | AMS1117 | 2
STC8G1K08-SOP8 |  | U3 | SOP8 | STC8G1K08-SOP8 | 1
SFB9712-QFN28 |  | U4 | SFB9712 | SFB9712-QFN28 | 1
BL919833BA |  | U5 | BL9198 | BL919833BA | 1
hr6816 |  | U6 | HR6816 | hr6816 | 1
YK1801 |  | U7 | YK1801 | YK1801 | 1
HR6707 |  | U8 | HR6707 | HR6707 | 1
wd3703 |  | U9 | WD3703 | wd3703 | 1
USB-C | USB-C型母接口 | USB-C | type-c 24p 前插后贴 | USB-C/S | 1
HDR-1X2 | 2P接插件 | Vibration motor | HDR2.54-LI-2P | Header 2 | 1

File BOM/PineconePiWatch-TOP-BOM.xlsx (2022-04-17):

Comment | Description | Designator | Footprint | LibRef | Quantity
TXD144CF | 1.44寸TFT | 1.4TFT_128_128 | TXD144CF | TXD144CF | 1
1uF | 贴片电容 | C1 | C 0603_L | C | 1
100uF/10V | 贴片电解电容 | C2 | CM C(5*5.4) | CE_SMD | 1
104 | 贴片电容 | C3 | C 0603_L | C | 1
HDR-1X10 | 10P接插件 | FPC1 | FPC1.0-2H-WS-10P | Header 10 | 1
HDR-1X8 | 8P接插件 | GY-62 | 维特智能GY61/62 | Header 8 | 1
CH340G | 串口转USB | IC1 | SOP16_L | CH340G | 1
Blue | 贴片LED | LED1 | LED 0603B | LED-SMD | 1
Green | 贴片LED | LED2 | LED 0603G | LED-SMD | 1
SS8050 | 高频放大-NPN型 | Q1, Q2, Q3 | SOT23 | 8050-SMD | 3
1K | 贴片电阻 | R1, R16, R17 | R 0603_L | R | 3
10K | 贴片电阻 | R2, R8, R9, R10, R11, R12, R13, R14, R18, R19, R20 | R 0603_L | R | 11
10 | 贴片电阻 | R3 | R 0603_L | R | 1
12K | 贴片电阻 | R4, R6 | R 0603_L | R | 2
470 | 贴片电阻 | R5, R7 | R 0603_L | R | 2
ESP32-S Module |  | SOC | PCBComponent_1 | ESP32-S Module | 1
3x6x5 | 3x6轻触开关 | SW1, SW2 | TSW SMD-3*6*2.5 | TSW 3x6 | 2
HDR-1X4 | 4P接插件 | SW3 | 4Pin三段拨动开关 | Header 4 | 1
TF_Card | TF卡座 | TF_Card1 | Micro SD | TF_Card | 1

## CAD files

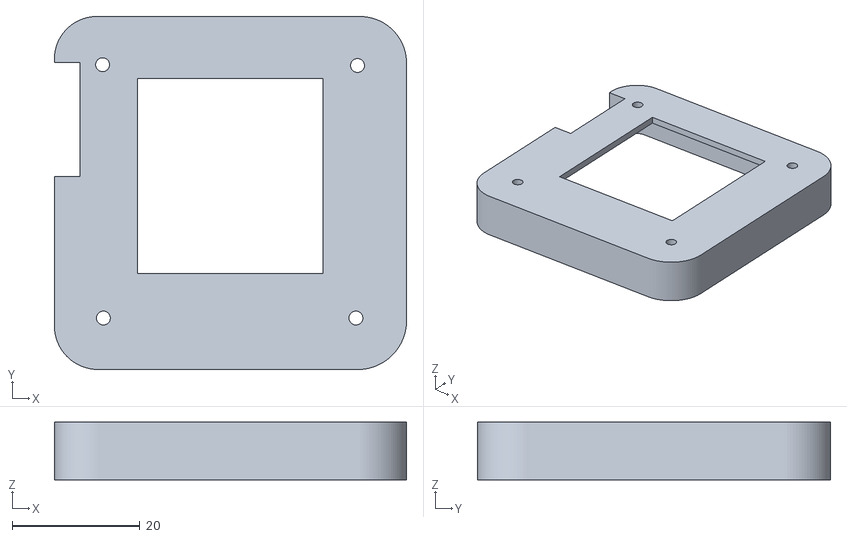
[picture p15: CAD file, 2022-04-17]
CASE/Top Case.stl
55.1 x 55.2 x 9.00

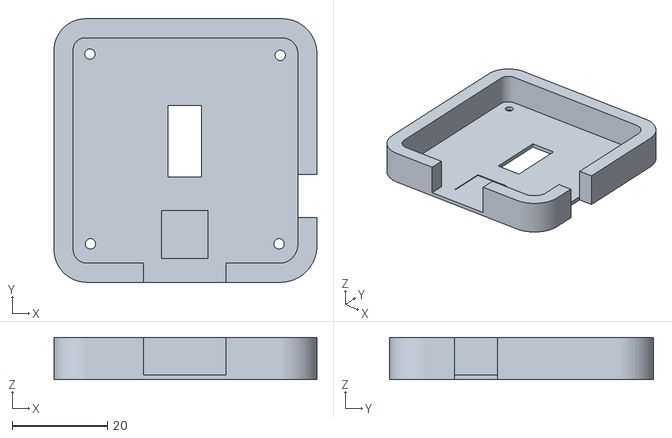
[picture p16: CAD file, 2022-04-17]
CASE/Bottom Case.stl
55.1 x 55.2 x 8.81

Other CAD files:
CODE/STC8-COPROCESSOR/co-stc/Objects/main.obj

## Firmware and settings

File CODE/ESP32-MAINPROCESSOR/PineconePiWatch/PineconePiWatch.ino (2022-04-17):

#define DebugPrintln(message) Serial.println(message)
#define DebugPrint(message) Serial.print(message)


/**************************TFT屏幕部分******************************/
#include <SPI.h>
#include <TFT_eSPI.h>
void tft_init(void); //tft初始化函数
TFT_eSPI tft = TFT_eSPI();  // Invoke custom library
void tft_init()//屏幕初始化
{
  
 tft.init();
 tft.setSwapBytes(true);
 tft.invertDisplay( false );
 tft.fillScreen(TFT_BLACK);
 tft.setCursor(0, 0, 2);
 tft.setTextColor(TFT_WHITE, TFT_BLACK);
 tft.print("TFT Init...[");
 tft.setTextColor(TFT_BLUE, TFT_BLACK);
 tft.print("X");
 tft.setTextColor(TFT_WHITE, TFT_BLACK);
 tft.println("]");
}

#include <JPEGDecoder.h>
void drawSdJpeg(const char *filename, int xpos, int ypos) {
  uint32_t readTime = millis();
  // Open the named file (the Jpeg decoder library will close it)
  File jpegFile = SD.open( filename, FILE_READ);  // or, file handle reference for SD library
  if ( !jpegFile ) {
    DebugPrint("ERROR: File \"");
    DebugPrint(filename);
    DebugPrintln ("\" not found!");
    return;
  }
  DebugPrintln("===========================");
  DebugPrint("Drawing file: "); DebugPrintln(filename);
  DebugPrintln("===========================");
  // Use one of the following methods to initialise the decoder:
  boolean decoded = JpegDec.decodeSdFile(jpegFile);  // Pass the SD file handle to the decoder,
  //boolean decoded = JpegDec.decodeSdFile(filename);  // or pass the filename (String or character array)
  //SD_read_Time(millis() - readTime);
  if (decoded) {
    // print information about the image to the serial port
    //jpegInfo();
    // render the image onto the screen at given coordinates
    jpegRender(xpos, ypos);
  }
  else {
    DebugPrintln("Jpeg file format not supported!");
  }
}
 
//####################################################################################################
// Draw a JPEG on the TFT, images will be cropped on the right/bottom sides if they do not fit
//####################################################################################################
// This function assumes xpos,ypos is a valid screen coordinate. For convenience images that do not
// fit totally on the screen are cropped to the nearest MCU size and may leave right/bottom borders.
void jpegRender(int xpos, int ypos) {
  // record the current time so we can measure how long it takes to draw an image
  uint32_t drawTime = millis();
  //jpegInfo(); // Print information from the JPEG file (could comment this line out)
  uint16_t *pImg;
  uint16_t mcu_w = JpegDec.MCUWidth;
  uint16_t mcu_h = JpegDec.MCUHeight;
  uint32_t max_x = JpegDec.width;
  uint32_t max_y = JpegDec.height;
  bool swapBytes = tft.getSwapBytes();
  tft.setSwapBytes(true);
  // Jpeg images are draw as a set of image block (tiles) called Minimum Coding Units (MCUs)
  // Typically these MCUs are 16x16 pixel blocks
  // Determine the width and height of the right and bottom edge image blocks
  uint32_t min_w = (mcu_w<(max_x % mcu_w)?mcu_w:(max_x % mcu_w));
  uint32_t min_h = (mcu_h<(max_y % mcu_h)?mcu_h:(max_y % mcu_h));
  // save the current image block size
  uint32_t win_w = mcu_w;
  uint32_t win_h = mcu_h;
  // save the coordinate of the right and bottom edges to assist image cropping
  // to the screen size
  max_x += xpos;
  max_y += ypos;
  // Fetch data from the file, decode and display
  while (JpegDec.read()) {    // While there is more data in the file
    pImg = JpegDec.pImage ;   // Decode a MCU (Minimum Coding Unit, typically a 8x8 or 16x16 pixel block)
    // Calculate coordinates of top left corner of current MCU
    int mcu_x = JpegDec.MCUx * mcu_w + xpos;
    int mcu_y = JpegDec.MCUy * mcu_h + ypos;
    // check if the image block size needs to be changed for the right edge
    if (mcu_x + mcu_w <= max_x) win_w = mcu_w;
    else win_w = min_w;
    // check if the image block size needs to be changed for the bottom edge
    if (mcu_y + mcu_h <= max_y) win_h = mcu_h;
    else win_h = min_h;
    // copy pixels into a contiguous block
    if (win_w != mcu_w)
    {
      uint16_t *cImg;
      int p = 0;
      cImg = pImg + win_w;
      for (int h = 1; h < win_h; h++)
      {
        p += mcu_w;
        for (int w = 0; w < win_w; w++)
        {
          *cImg = *(pImg + w + p);
          cImg++;
        }
      }
    }
    // calculate how many pixels must be drawn
    uint32_t mcu_pixels = win_w * win_h;
    // draw image MCU block only if it will fit on the screen
    if (( mcu_x + win_w ) <= tft.width() && ( mcu_y + win_h ) <= tft.height())
      tft.pushImage(mcu_x, mcu_y, win_w, win_h, pImg);
    else if ( (mcu_y + win_h) >= tft.height())
      JpegDec.abort(); // Image has run off bottom of screen so abort decoding
  }
  tft.setSwapBytes(swapBytes);
  //showTime(millis() - drawTime); //将图片显示到屏幕所用的时间(ms)
}
/**************************TFT屏幕部分******************************/
/**************************SD卡部分******************************/
#include <SD.h>
#include <FS.h>
SPIClass sdSPI(VSPI);
#define SD_MISO     19
#define SD_MOSI     23
#define SD_SCLK     18
#define SD_CS       5
void TFCard_Init(void);
void TFCard_Init()
{
  sdSPI.begin(SD_SCLK, SD_MISO, SD_MOSI, SD_CS);
  delay(100);
  if (!SD.begin(SD_CS, sdSPI))
  {
    //tft.println("存储卡挂载失败");
    tft.println("TF Card Init...[ ]");
    return;
  }
  uint8_t cardType = SD.cardType();
 
  if (cardType == CARD_NONE)
  {
    //tft.println("未连接存储卡");
    tft.println("TF Card Init...[ ]");
    return;
  }
  else if (cardType == CARD_MMC)
  {
    //tft.println("挂载了MMC卡");
  }
  else if (cardType == CARD_SD)
  {
    //tft.println("挂载了SDSC卡");
  }
  else if (cardType == CARD_SDHC)
  {
    //tft.println("挂载了SDHC卡");
  }
  else
  {
    //tft.println("挂载了未知存储卡");
  }
  //char sd_size_string[30];
  //sprintf(sd_size_string,"TF Card Init ...[X] = %ld MB",SD.cardSize()/(1024*1024));
 tft.setTextColor(TFT_WHITE, TFT_BLACK);
 tft.print("TF Card Init...[");
 tft.setTextColor(TFT_BLUE, TFT_BLACK);
 tft.print("X");
 tft.setTextColor(TFT_WHITE, TFT_BLACK);
 tft.println("]"); 
}
/**************************SD卡部分******************************/
/**************************按钮部分******************************/
byte UserButton_Press_Down_flag = 0; //按钮按下标志位
byte UserButton_Left_Press_Down_flag = 0; //按钮上拨标志位
byte UserButton_Right_Press_Down_flag = 0; //按钮下拨标志位
void UserButton_Init()
{
  pinMode(33, INPUT|PULLUP ); // Press Down
  pinMode(32, INPUT|PULLUP ); // Left Press Down
  pinMode(34, INPUT|PULLUP ); // Right Press Down
  attachInterrupt(33, UserButton_Press_Down, FALLING); // negedge
  attachInterrupt(32, UserButton_Left_Press_Down, FALLING); // negedge
  attachInterrupt(34, UserButton_Right_Press_Down, FALLING); // negedge
  tft.setTextColor(TFT_WHITE, TFT_BLACK);
  tft.print("Button Init...[");
  tft.setTextColor(TFT_BLUE, TFT_BLACK);
  tft.print("X");
  tft.setTextColor(TFT_WHITE, TFT_BLACK);
  tft.println("]");
}
void UserButton_Press_Down()
{
  UserButton_Press_Down_flag = 1;
}
void UserButton_Left_Press_Down()
{
  UserButton_Left_Press_Down_flag = 1;
}
void UserButton_Right_Press_Down()
{
  UserButton_Right_Press_Down_flag = 1;
}
/**************************按钮部分******************************/
/**************************LED部分******************************/
//上绿下蓝
#define LED_Green 26
#define LED_Blue 27
void LED_Init()
{
  pinMode(LED_Green, OUTPUT); // Blue LED
  pinMode(LED_Blue, OUTPUT); // Green LED
  digitalWrite(LED_Green, HIGH);    // turn the LED off by making the voltage LOW
  digitalWrite(LED_Blue, HIGH);    // turn the LED off by making the voltage LOW
  tft.setTextColor(TFT_WHITE, TFT_BLACK);
  tft.print("LED Init...[");
  tft.setTextColor(TFT_BLUE, TFT_BLACK);
  tft.print("X");
  tft.setTextColor(TFT_WHITE, TFT_BLACK);
  tft.println("]");
}
/**************************LED部分******************************/
/**************************震动马达部分******************************/
//上绿下蓝
#define shake_motor 12
void shake_motor_Init()
{
  pinMode(shake_motor, OUTPUT); // shake_motor
  digitalWrite(shake_motor, LOW);    // turn the shake_motor off by making the voltage LOW
  tft.setTextColor(TFT_WHITE, TFT_BLACK);
  tft.print("Shake Motor Init...[");
  tft.setTextColor(TFT_BLUE, TFT_BLACK);
  tft.print("X");
  tft.setTextColor(TFT_WHITE, TFT_BLACK);
  tft.println("]");
}
/**************************震动马达部分******************************/

/**************************陀螺仪+加速度计部分+LOG打印******************************/
#include <Wire.h>
#include "JY901.h"
#include <HardwareSerial.h> 

HardwareSerial Serial_2(2);//串口2
int GY_60_available = 0;//0无效 1有效
void GY_60_Init()
{
  Serial.begin(115200);
  Serial_2.begin(9600);
  delay(50);
  GY_60_Event();
  if(GY_60_available == 1)
  {
  tft.setTextColor(TFT_WHITE, TFT_BLACK);
  tft.print("Sensor1 Init...[");
  tft.setTextColor(TFT_BLUE, TFT_BLACK);
  tft.print("X");
  tft.setTextColor(TFT_WHITE, TFT_BLACK);
  tft.println("]");
  }
  else if(GY_60_available == 0)
  {
  tft.setTextColor(TFT_WHITE, TFT_BLACK);
  tft.print("Sensor1 Init...[");
  tft.setTextColor(TFT_BLUE, TFT_BLACK);
  tft.print(" ");
  tft.setTextColor(TFT_WHITE, TFT_BLACK);
  tft.println("]");
  }
}
void GY_60_Event()//解析GY60的数据
{
  while (Serial_2.available()) 
  {
    GY_60_available = 1;
    JY901.CopeSerialData(Serial_2.read()); //Call JY901 data cope function
  }
}

/**************************陀螺仪+加速度计部分+LOG打印******************************/
/**************************心率 血压(软串口连接STC  )******************************/
#include <Wire.h>
#define Systolic_bit 0x01
#define Diastolic_bit 0x02
#define heart_bit 0x03
#define temp_h 0x04
#define temp_l 0x05
#define wave_h 0x11
#define wave_l 0x12

#define sensor_status 0x07
#define tft_bit 0x08
#define sensor_bit 0x09
#define stc_sleep_bit 0x10

#define enable_co 0x01
#define disable_co 0x00

uint8_t error;
uint8_t i2cAddress = 0x2d;//2d

unsigned char sensor_data[8];
  float temp = 0.0;//体温
  int heart = 0;//心率
  int Systolic = 0;//收缩压
  int Diastolic = 0;//舒张压
  unsigned char i = 0;
void sensor2_init()
{
  Wire.begin();
  Wire.beginTransmission(i2cAddress);
  //Wire.write(0x09);
  //Wire.write(0x01);
  error = Wire.endTransmission();
  //Wire.requestFrom(i2cAddress, 1);
  //if(Wire.available() >= 1)
  //{
   //status = Wire.read(); 
   //Serial.println(status, HEX);
  //}
  Serial.println(error);
  if(error == 0)//收到了ACK数据
  {
  tft.setTextColor(TFT_WHITE, TFT_BLACK);
  tft.print("Sensor2 Init...[");
  tft.setTextColor(TFT_BLUE, TFT_BLACK);
  tft.print("X");
  tft.setTextColor(TFT_WHITE, TFT_BLACK);
  tft.println("]");
  return;  
  }
  else
  {
  tft.setTextColor(TFT_WHITE, TFT_BLACK);
  tft.print("Sensor2 Init...[");
  tft.setTextColor(TFT_BLUE, TFT_BLACK);
  tft.print(" ");
  tft.setTextColor(TFT_WHITE, TFT_BLACK);
  tft.println("]");
  return;
  }    
  
  /*
  if (nDevices == 0)
    Serial.println("No I2C devices found\n");
  else
    Serial.println("done\n");
    */
}
void tft_switch(unsigned char onoff)
{
  if(onoff == 1)
  {
    Wire.beginTransmission(i2cAddress);
    Wire.write(tft_bit);
    Wire.write(enable_co);
    error = Wire.endTransmission();
  }
  else
  {
    Wire.beginTransmission(i2cAddress);
    Wire.write(tft_bit);
    Wire.write(disable_co);
    error = Wire.endTransmission();
  }
}
void sensor_switch(unsigned char onoff)
{
  if(onoff == 1)
  {
    Wire.beginTransmission(i2cAddress);
    Wire.write(sensor_bit);//0x55
    Wire.write(enable_co);
    error = Wire.endTransmission();
  }
  else
  {
    Wire.beginTransmission(i2cAddress);
    Wire.write(sensor_bit);
    Wire.write(disable_co);
    error = Wire.endTransmission();
  }
}
void stc_switch(unsigned char onoff)
{
  if(onoff == 1)
  {
    Wire.beginTransmission(i2cAddress);
    Wire.write(stc_sleep_bit);
    Wire.write(enable_co);
    error = Wire.endTransmission();
  }
  else
  {
    /*先发一个数据唤醒下*/
    Wire.beginTransmission(i2cAddress);
    Wire.write(0x55);
    error = Wire.endTransmission();
    /*然后在把控制位关掉*/
    Wire.beginTransmission(i2cAddress);
    Wire.write(stc_sleep_bit);
    Wire.write(disable_co);
    error = Wire.endTransmission();
  }
}
void sensor2_handle()
{
    for(i=0x01;i<=0x05;i++)
    {
      Wire.beginTransmission(i2cAddress);
      Wire.write(i);
      Wire.endTransmission();
      Wire.requestFrom(i2cAddress, 1);
      if(Wire.available() >= 1)
      {
        sensor_data[i] = Wire.read(); 
        //Serial.print(i);
        //Serial.print("|");
        //Serial.println(sensor_data[i], HEX);
      }
    }
    
    temp = (sensor_data[0x04]*256+sensor_data[0x05])/256;
    if(sensor_data[0x01]<250)
    {
      Systolic = sensor_data[0x01];
    }
    if(sensor_data[0x02]<250)
    {
      Diastolic = sensor_data[0x02];
    }
    if(sensor_data[0x03]<250)
    {
      heart = sensor_data[0x03];
    }
    Serial.print("heart:");
    Serial.print(heart);
    Serial.print("|");
    Serial.print("temp:");
    Serial.println(temp);
    //Serial.printf("Systolic:%d|Diastolic:%d|heart:%d|temp:%f.\r\n",Systolic,Diastolic,heart,temp);
}
/**************************心率 血压******************************/
/**************************WIFI与NTP时间******************************/
#include <WiFi.h>
#include <PubSubClient.h> //MQTT库函数
#include "time.h"
 
const char* ssid       = "TP-LINK_18A1";
const char* password   = "dl742163";

const char* mqtt_server = "47.242.51.78";//mqtt服务器IP地址
const int mqttPort = 1883;//mqtt服务器端口地址

WiFiClient espClient;
PubSubClient client(espClient);

const char* ntpServer = "pool.ntp.org";
const long  gmtOffset_sec = 28800;
const int   daylightOffset_sec = 0;
int wifi_tick = 0;
int request_status = 0;//服务器请求设备发送自己的数据
void wifi_init()
{
  WiFi.begin(ssid, password);
  while (WiFi.status() != WL_CONNECTED) {
      delay(500);
      Serial.print(".");
      wifi_tick++;
      if(wifi_tick == 10)//尝试10次重连，无法连接则跳过
      {
      return;
      }
      //WiFi.begin(ssid, password);
  }
  Serial.println("WIFI CONNECTED");
  
   //WIFI路由器连接成功后,连接MQTT服务器
  client.setServer(mqtt_server, mqttPort);
  client.setCallback(callback);
  while (!client.connected()) {
    if (client.connect("PineconePiWatch")) {
      //成功连接MQTT服务器
    } else {
      //不成功连接MQTT服务器则每隔2秒重试一次
      delay(2000);
    }
  }
 
  client.publish("PineconePi/Watch", "PineconePi Watch Online!");//设备上线
  client.subscribe("PineconePi/Watch");//订阅mqtt服务器PineconePi/Watch主题
  
  //init and get the time
  configTime(gmtOffset_sec, daylightOffset_sec, ntpServer);
  //printLocalTime();
 
  //disconnect WiFi as it's no longer needed
  //WiFi.disconnect(true);
  //WiFi.mode(WIFI_OFF);

}
void callback(char* topic, byte* payload, unsigned int length) {//接收mqtt返回的数据
  //mqtt指令表
  //a:开机 b:关机 
  //c:上一界面 d:下一个界面
 char command = (char)payload[0];
 switch(command)//根据网页上发来的命令做相应处理
 {
  case 'a':break;
  case 'b':break;

  case 'c':break;
  case 'd':break;

  case 'z':request_status = 1;break;
  default:break;
 }
}
void printLocalTime()
{
  struct tm timeinfo;
  if(!getLocalTime(&timeinfo)){
    Serial.println("Failed to obtain time");
    return;
  }
  //Serial.println(&timeinfo, "%A, %Y-%m-%d %H:%M:%S");
  char ntp_time_string[50];
  sprintf(ntp_time_string,"%d:%d:%d",timeinfo.tm_hour,timeinfo.tm_min,timeinfo.tm_sec);
  //打印存储卡信息
  tft.println(ntp_time_string); 
}
/**************************WIFI与NTP时间******************************/
/**************************显示开机LOGO******************************/
void show_logo()
{
  tft.fillScreen(TFT_BLACK);
  digitalWrite(shake_motor, HIGH);    // turn the shake_motor on by making the voltage HIGH
  drawSdJpeg("/sys/logo.jpg", 0, 0);     // This draws a jpeg pulled off the SD Card
  digitalWrite(LED_Green, LOW);    // turn the LED off by making the voltage LOW
  digitalWrite(LED_Blue, LOW);    // turn the LED off by making the voltage LOW
}
/**************************显示开机LOGO******************************/
/**************************ULP部分******************************/
#include "esp32/ulp.h"
#include "driver/rtc_io.h"
#include "UlpDebug.h" //ULP调试器输出
//#include "UlpDebug.h"
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
void loop()//main
{
  // Empty. Things are done in Tasks.
}


/*--------------------------------------------------*/
/*---------------------- Tasks ---------------------*/
/*--------------------------------------------------*/


void TaskUI(void *pvParameters)  // This is a task.
{
  (void) pvParameters;
  BaseType_t xStatus;
  const TickType_t xTicksToWait = pdMS_TO_TICKS(50);  //这里就是用于取数据阻塞了，我觉得本来这种收发就不可能同步，但是应该接收来满足发送，接收速度大于发送速度才行
  int status_ui = 1;
  while(1)
  {
  xStatus = xQueueReceive( xqueue0, &status_ui, xTicksToWait );  
  if(status_ui == 1)
  drawSdJpeg("/sys/status.jpg", 0, 0);//状态
  else if(status_ui == 2)
  drawSdJpeg("/sys/health.jpg", 0, 0);//健康
  else if(status_ui == 3)
  drawSdJpeg("/sys/sport.jpg", 0, 0);//运动
  else if(status_ui == 4)
  drawSdJpeg("/sys/weather.jpg", 0, 0);//天气
  else if(status_ui == 5)
  drawSdJpeg("/sys/notice.jpg", 0, 0);//通知
  else if(status_ui == 6)
  drawSdJpeg("/sys/more.jpg", 0, 0);//更多
  else if(status_ui == 7)
  {
  tft.fillScreen(TFT_BLACK);
  tft.setCursor(0, 0);
  printLocalTime();
  //tft.println("Body Test");//更多
  tft.print("Systolic:");
  tft.println(Systolic);//更多
  tft.print("Diastolic:");
  tft.println(Diastolic);//更多
  tft.setTextColor(TFT_WHITE, TFT_BLACK);
  tft.setTextColor(TFT_RED, TFT_BLACK);
  tft.print("H:");//更多
  tft.setTextColor(TFT_WHITE, TFT_BLACK);
  tft.print(heart);//更多
  tft.print("|");//更多
  tft.setTextColor(TFT_BLUE, TFT_BLACK);
  tft.print("T:");//更多
  tft.setTextColor(TFT_WHITE, TFT_BLACK);
  tft.println(temp);//更多
  tft.print("Angle:");tft.println("  Gyro:");
  tft.print((float)JY901.stcAngle.Angle[0]/32768*180);tft.print("   ");tft.println((float)JY901.stcGyro.w[0]/32768*2000);
  tft.print((float)JY901.stcAngle.Angle[1]/32768*180);tft.print("   ");tft.println((float)JY901.stcGyro.w[1]/32768*2000);
  tft.print((float)JY901.stcAngle.Angle[2]/32768*180);tft.print("   ");tft.println((float)JY901.stcGyro.w[2]/32768*2000);
  }
  else if(status_ui == 8)
  {
    tft_switch(0);
    sensor_switch(0);
    stc_switch(0);
    esp_sleep_enable_ext0_wakeup(GPIO_NUM_32, 0);  
    esp_sleep_enable_ext0_wakeup(GPIO_NUM_33, 0);
    esp_sleep_enable_ext0_wakeup(GPIO_NUM_34, 0);
    esp_deep_sleep_start();//开始休眠
  }
  }
}

void TaskLED(void *pvParameters)  // This is a task.
{
  (void) pvParameters;
  const TickType_t xTicksToWait = pdMS_TO_TICKS(100);   // 阻止任务的时间，直到队列有空闲空间 ，应该是如果发送需要阻滞等待（比如队列满了）或者别的情况需要用到的
  int status_ui = 1;
  BaseType_t xStatus;
  char Data_String[200];//温湿度和设备状态字符数组
  float AngleX=0.0,AngleY=0.0,AngleZ=0.0;
  float GyroX=0.0,GyroY=0.0,GyroZ=0.0;

  while(1) // A Task shall never return or exit.
  {    
    GY_60_Event();//解析GY60的数据
    sensor2_handle();
    digitalWrite(LED_Green, HIGH);   // turn the LED on (HIGH is the voltage level)
    digitalWrite(LED_Blue, HIGH);   // turn the LED on (HIGH is the voltage level)
    vTaskDelay(100);  // one tick delay (15ms) in between reads for stability
    digitalWrite(LED_Green, LOW);    // turn the LED off by making the voltage LOW
    digitalWrite(LED_Blue, LOW);   // turn the LED on (HIGH is the voltage level)
    vTaskDelay(100);  // one tick delay (15ms) in between reads for stability
    /***********************************mqtt****************************************/
    client.loop();//mqtt服务器心跳包
    if(request_status == 1)//request_status == 0
    {
    AngleX = (float)JY901.stcAngle.Angle[0]/32768*180;
    GyroX = (float)JY901.stcGyro.w[0]/32768*2000;

    AngleY = (float)JY901.stcAngle.Angle[1]/32768*180;
    GyroY = (float)JY901.stcGyro.w[1]/32768*2000;
    
    AngleZ = (float)JY901.stcAngle.Angle[2]/32768*180;
    GyroZ = (float)JY901.stcGyro.w[2]/32768*2000;
    
    sprintf(Data_String,"T:%f|H:%d|Systolic:%d|Diastolic:%d|Angle-X:%f|Angle-Y:%f|Angle-Z:%f|Gyro-X:%f|Gyro-Y:%f|Gyro-Z:%f",temp,heart,Systolic,Diastolic,AngleX,AngleY,AngleZ,GyroX,GyroY,GyroZ);//拼接设备状态字符串
    client.publish("PineconePi/Watch", Data_String);//将温湿度数据发送给mqtt服务器
    request_status = 0;//清除状态位
    }
    
    /********************按钮消抖触发************************/
    if(UserButton_Press_Down_flag == 1)//按钮按下
    {
      vTaskDelay(10);
      if((UserButton_Press_Down_flag == 1)&&(digitalRead(33)==LOW))
      {
        attachInterrupt(33, UserButton_Press_Down, RISING); // negedge
        UserButton_Press_Down_flag = 0;
      }
      if((UserButton_Press_Down_flag == 1)&&(digitalRead(33)==HIGH))
      {
        attachInterrupt(33, UserButton_Press_Down, FALLING); // negedge
        Serial.print("freeretos:用户按钮按下");//用户按钮按下
        UserButton_Press_Down_flag = 0;
      }
    } 
    if(UserButton_Left_Press_Down_flag == 1)//上拨
    {
      vTaskDelay(10);
      if((UserButton_Left_Press_Down_flag == 1)&&(digitalRead(32)==LOW))
      {
        attachInterrupt(32, UserButton_Left_Press_Down, RISING); // negedge
        UserButton_Left_Press_Down_flag = 0;
      }
      if((UserButton_Left_Press_Down_flag == 1)&&(digitalRead(32)==HIGH))
      {
        attachInterrupt(32, UserButton_Left_Press_Down, FALLING); // negedge
        Serial.print("freeretos:用户按钮上拨");//用户按钮上拨
        UserButton_Left_Press_Down_flag = 0;
        status_ui--;
        
        if(status_ui<1)status_ui=7;
        xStatus = xQueueSendToFront( xqueue0, &status_ui, xTicksToWait );
      }
    } 
    if(UserButton_Right_Press_Down_flag == 1)//下拨
    {
      vTaskDelay(10);
      if((UserButton_Right_Press_Down_flag == 1)&&(digitalRead(34)==LOW))
      {
        attachInterrupt(34, UserButton_Right_Press_Down, RISING); // negedge
        UserButton_Right_Press_Down_flag = 0;
      }
      if((UserButton_Right_Press_Down_flag == 1)&&(digitalRead(34)==HIGH))
      {
        attachInterrupt(34, UserButton_Right_Press_Down, FALLING); // negedge
        Serial.print("freeretos:用户按钮下拨");//按钮按下
        UserButton_Right_Press_Down_flag = 0;
        status_ui++;
        
        if(status_ui>7)status_ui=1;
        xStatus = xQueueSendToFront( xqueue0, &status_ui, xTicksToWait );
      }
    }     


    
  }
}

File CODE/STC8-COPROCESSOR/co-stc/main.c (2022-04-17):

#include "stc8g.h"
#include "intrins.h"
/*
0x01 收缩压
0x02 舒张压
0x03 心率
0x04 温度高位
0x05 温度低位
0x11 脉搏波高八位
0x12 脉搏波高八位

0x07 佩戴检测
0x08 tft背光
0x09 sensor 电源
0x10 stc8g 睡眠
*/
#define Systolic_bit 0x01
#define Diastolic_bit 0x02
#define heart_bit 0x03
#define temp_h 0x04
#define temp_l 0x05
#define wave_h 0x11
#define wave_l 0x12

#define status 0x07
#define tft_bit 0x08
#define sensor_bit 0x09
#define stc_sleep_bit 0x10
sbit 		sensor_power_control = P3^3;
sbit 		tft_power_control = P3^2;

#define MAIN_Fosc		11059200L	//定义主时钟
typedef unsigned char u8;
/*MK0908命令表*/
unsigned char get_data[] ={0xFD,0X00,0X00,0X00,0X00,0X00};//获取心率血压温度
unsigned char get_wave[] ={0xFC,0X00,0X00,0X00,0X00,0X00};//脉搏波读取
unsigned char get_status[] ={0xF8,0X00,0X00,0X00,0X00,0X00};//模块工作状态读取

unsigned char receive_buffer[6];
unsigned char data_i = 0;//字节计数
unsigned char receive_success = 0;//接收完成


bit isda;                                       //设备地址标志
bit isma;                                       //存储地址标志
unsigned char addr;
unsigned char pdata buffer[256];

void Delay_ms(unsigned int ms)		//@11.0592MHz
{
	unsigned char i, j,k;
	for(k=0;k<ms;k++)
	{
		i = 15;
		j = 90;
		do
		{
			while (--j);
		} while (--i);
	}
}

void I2C_Isr() interrupt 24
{
    if (I2CSLST & 0x40)
    {
        I2CSLST &= ~0x40;                       //处理START事件
    }
    else if (I2CSLST & 0x20)
    {
        I2CSLST &= ~0x20;                       //处理RECV事件
        if (isda)
        {
            isda = 0;                           //处理RECV事件（RECV DEVICE ADDR）
        }
        else if (isma)
        {
            isma = 0;                           //处理RECV事件（RECV MEMORY ADDR）
            addr = I2CRXD;
            I2CTXD = buffer[addr];
        }
        else
        {
            buffer[addr++] = I2CRXD;            //处理RECV事件（RECV DATA）
        }
    }
    else if (I2CSLST & 0x10)
    {
        I2CSLST &= ~0x10;                       //处理SEND事件
        if (I2CSLST & 0x02)
        {
            I2CTXD = 0xff;
        }
        else
        {
            I2CTXD = buffer[++addr];
        }
    }
    else if (I2CSLST & 0x08)
    {
        I2CSLST &= ~0x08;                       //处理STOP事件
        isda = 1;
        isma = 1;
    }
   // _pop_(P_SW2);
}
void mk0809_send_command(unsigned char command[])
{
	unsigned char i = 0;
	for(i=0;i<6;i++)
	{
		SBUF = command[i];//发送MK0908命令
		while(!TI);
		TI = 0;
	}
}
void gpio_init()
{
		P3M0 = 0x00;                                //设置P3.0~P3.7为双向口模式
    P3M1 = 0x00;
		P5M0 = 0x00;                                //设置P5.0~P5.7为双向口模式
    P5M1 = 0x00;
		P_SW2 = 0x10;                               //IIC引脚切换
		P_SW2 |= 0x80;                              //允许写入IIC相关寄存器
}
void UART1_Isr() interrupt 4
{
    if (TI)
    {
      TI = 0;                                 //清中断标志
    }
    if (RI)
    {
			receive_buffer[data_i] = SBUF;
			data_i++;
			if(data_i>=6)
			{
				data_i = 0;
				receive_success = 1;
			}
      RI = 0;                                 //清中断标志
    }
}

void main()
{		
		u8 time_over = 0;
		u8 data_iic = 0x55;
		gpio_init();
		/*UART-115200*/
		SCON = 0x50;		//8位数据,可变波特率
		AUXR |= 0x40;		//定时器1时钟为Fosc,即1T
		AUXR &= 0xFE;		//串口1选择定时器1为波特率发生器
		TMOD &= 0x0F;		//设定定时器1为16位自动重装方式
		TL1 = 0xE8;		//设定定时初值
		TH1 = 0xFF;		//设定定时初值
		ET1 = 0;		//禁止定时器1中断
		TR1 = 1;		//启动定时器1
		ES=1;
		/*iic*/
	  I2CCFG = 0x81;                              //使能I2C从机模式
    I2CSLADR = 0x5a;                            //设置从机设备地址为5A
    I2CSLST = 0x00;
    I2CSLCR = 0x78;                             //使能从机模式中断
    EA = 1;
    isda = 1;                                   //用户变量初始化
    isma = 1;
    addr = 0;
    I2CTXD = buffer[addr];
	  buffer[tft_bit] = 1;//背光默认开启	
		buffer[sensor_bit] = 0;//传感器电源默认关闭
		buffer[stc_sleep_bit] = 0;//stc掉电睡眠模式关闭
		
		buffer[Systolic_bit] = 0;
		buffer[Diastolic_bit] = 0;
		buffer[heart_bit] = 0;
		buffer[temp_h] = 0;
		buffer[temp_l] = 0;
		buffer[wave_h] = 0;
		buffer[wave_l] = 0;
		buffer[status] = 0;
    while (1)
		{	
			if(buffer[tft_bit] == 1)
			{
				tft_power_control = 1;
			}
			else
			{
				tft_power_control = 0;
			}
			
			if(buffer[sensor_bit] == 1)
			{
				sensor_power_control = 1;
			}
			else
			{
				sensor_power_control = 0;
			}
			
			if(buffer[stc_sleep_bit] == 1)
			{
					PCON = 0X02; //进入掉电模式
			}
			else
			{
				
			}
			/*以下这段程序指针越界会跑死(回家调)*/
			if(buffer[sensor_bit] == 1)
			{
					mk0809_send_command(get_data);//获取数据
					//while(!(receive_success==1));//等待接收完成再去解析数据
					Delay_ms(200);
					time_over = 0; //清除超时跳过标志
					if(receive_success == 1)
					{
						buffer[Systolic_bit]=receive_buffer[1];
						buffer[Diastolic_bit]=receive_buffer[2];
						buffer[heart_bit]=receive_buffer[3];
						buffer[temp_h]=receive_buffer[4];
						buffer[temp_l]=receive_buffer[5];
						receive_success=0;
					}
					
					/*
					mk0809_send_command(get_wave);//获取波
					Delay_ms(200);
					//while(!(receive_success==1));//等待接收完成再去解析数据
					time_over = 0; //清除超时跳过标志
					if(receive_success == 1)
					{
						buffer[wave_h]=receive_buffer[2];
						buffer[wave_l]=receive_buffer[3];
						receive_success=0;
					}
					
					
					mk0809_send_command(get_status);//获佩戴状态
					Delay_ms(200);
					//while(!(receive_success==1));//等待接收完成再去解析数据
					time_over = 0; //清除超时跳过标志
					if(receive_success == 1)
					{
						buffer[status]=receive_buffer[3];
						receive_success=0;
					}
					*/
					Delay_ms(50);//总体延迟50ms
			}
	}
}

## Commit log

2022-04-17 upload sch
    [PineconePiWatch-Bottom.SchDoc, PineconePiWatch-Top.SchDoc]
2022-12-29 upload other resources
    [敏捷甘特图1.xlsx, 甘特图-en.xlsx, 甘特图.xlsx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]
